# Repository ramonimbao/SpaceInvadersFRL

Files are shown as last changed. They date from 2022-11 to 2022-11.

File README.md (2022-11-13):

# Space Invaders FRL

  
Photo by migfernando#2194

## Disclaimer

Basically, the Space Invaders and the individual Space Invader icons belong solely to Taito Corporation, and cannot be included in this repository. 

## Files

### Case

Case files and drawings are in the `case` folder.

The files are designed for CNC machining and include the drawings for ttap callouts and such. For 3D printing, you may need to modify the files.

### Plate

Plate files are in the `plate` folder.

A DXF file is included for machining/laser cutting.

KiCAD files for an FR4 plate are in the `plate/sifrl-plate` folder. Gerber files are in the `plate/sifrl-plate/JLCPCB/gerbers` folder.

Either way, **order 1mm thick plates**.

### PCB

Main PCB files are in the `pcb` folder.

Gerber files are in the `pcb/JLCPCB/gerbers` folder. Assembly files are in `pcb/JLCPCB/assembly folder`.

A 1.6mm thick PCB should be fine. 1.2mm could work.

### Firmware

The keyboard uses [QMK/VIAL](https://get.vial.today/). Firmware file for it is in the `firmware` folder.

QMK source files for the board are in [this repo](https://github.com/ramonimbao/vial-qmk/tree/kb/sifrl/keyboards/ramonimbao/sifrl).

## Daughterboard

The board uses [my own version of the squatterboard](https://github.com/ramonimbao/squatterboard-v1.5). See the repo for more details.

## Parts Needed

| Qty | Part | URL | Notes |
| --- | ---- | --- | ----- |
| 2 | M3x10 Cap Head Screw | https://www.mcmaster.com/95263A134 | For the case |
| 9 | M2.5x6 Button Head Screw | https://www.mcmaster.com/92095A458 |For the plate |
| 2 | M3x6 Cap Head Screw | https://www.mcmaster.com/92095A179 | For the daughterboard
| 1 | 50mm 4-pin JST-SH cable | https://www.digikey.com/short/q0md9qh8 |  Longer is better if you want to be able to reassemble it often |

## License

The files in this repository are licensed under CERN-OHL-P-2.0. See the LICENSE file for more details.

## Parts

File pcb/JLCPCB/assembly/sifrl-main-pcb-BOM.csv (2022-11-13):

Comment | Designator | Footprint | LCSC
100nF | C1,C2,C4,C5,C6,C7,C8,C9,C10,C11,C17 | Capacitor_SMD:C_0402_1005Metric | C1525
30pF | C15,C16 | Capacitor_SMD:C_0402_1005Metric | C1570
1uF | C3,C12,C13,C14 | Capacitor_SMD:C_0603_1608Metric | C15849
1N4148 | D1,D2,D3,D4,D5,D6,D7,D8,D9,D10,D11,D12,D13,D14,D15,D16,D17,D18,D19,D20,D21,D22,D23,D24,D25,D26,D27,D28,D29,D30,D31,D32,D33,D34,D35,D36,D37,D38,D39,D40,D41,D42,D43,D44,D45,D46,D47,D48,D49,D50,D51,D52,D53,D54,D55,D56,D57,D58,D59,D60,D61,D62,D63,D64,D65,D66,D67,D68,D69,D70,D71,D72 | random-keyboard-parts:D_SOD-123-Pretty | C81598
500mA | F1 | Fuse:Fuse_1206_3216Metric_Pad1.42x1.75mm_HandSolder | C70076
SM04B | J1 | Connector_JST:JST_SH_SM04B-SRSS-TB_1x04-1MP_P1.00mm_Horizontal | C160404
10K | R1 | Resistor_SMD:R_0402_1005Metric | C25744
1k | R2 | Resistor_SMD:R_0402_1005Metric | C11702
27 | R3,R4 | Resistor_SMD:R_0603_1608Metric | C25190
SW_Push | SW1 | Button_Switch_SMD:SW_SPST_TL3342 | C318884
XC6206P332MR | U1 | Package_TO_SOT_SMD:SOT-23 | C5446
RP2040 | U2 | random-keyboard-parts:RP2040-QFN-56 | C2040
SRV05-4 | U3 | Package_TO_SOT_SMD:SOT-23-6 | C85364
W25Q128JVS | U4 | Package_SO:SOIC-8_5.23x5.23mm_P1.27mm | C97521
12MHz | Y1 | Crystal:Crystal_SMD_3225-4Pin_3.2x2.5mm | C9002

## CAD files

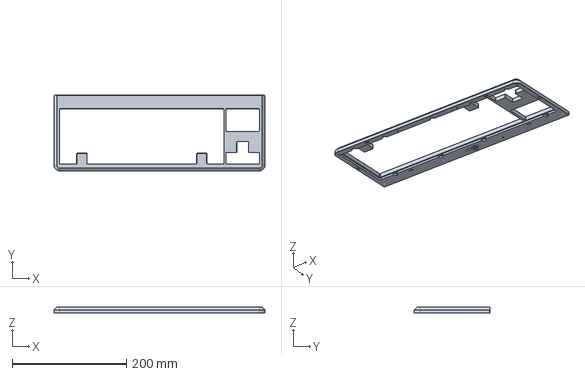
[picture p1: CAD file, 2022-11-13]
case/SI FRL - Top (WKL).step
368.7 x 132.3 x 10.5 mm

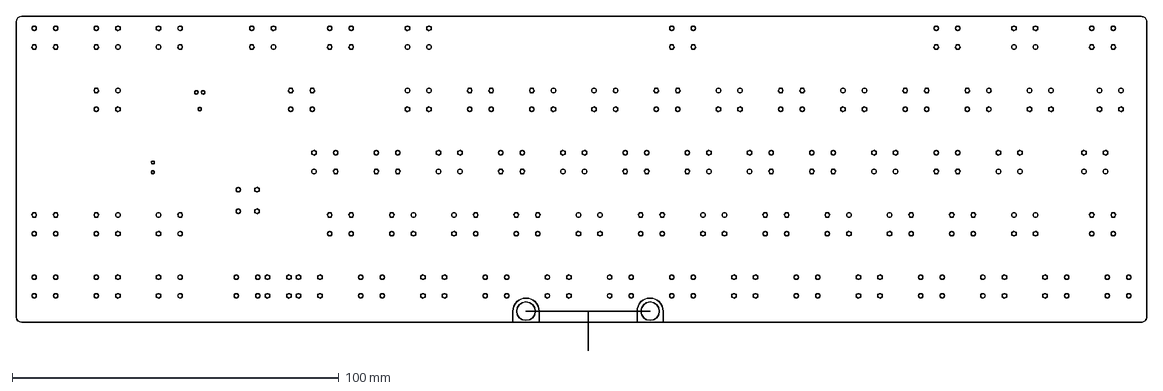
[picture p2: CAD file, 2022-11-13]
pcb/pcb-cutouts.dxf
346.1 x 102.3 mm

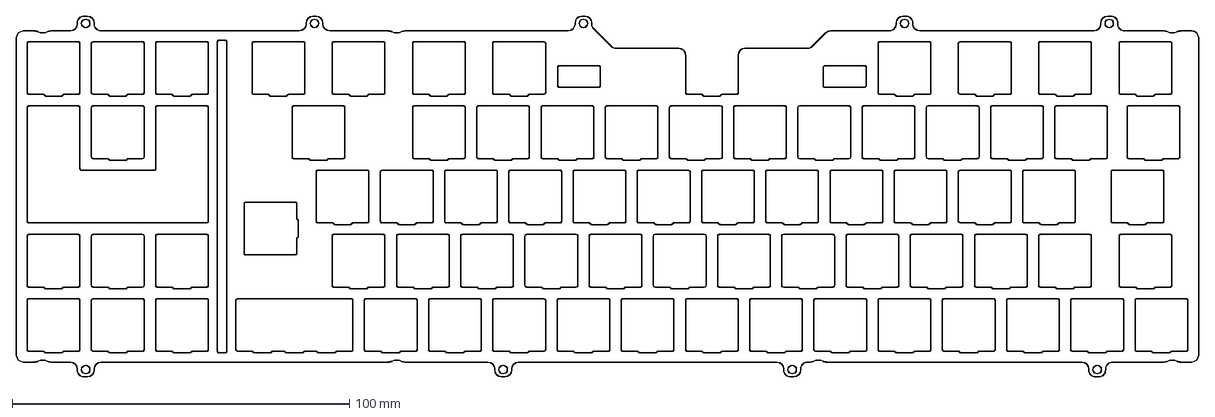
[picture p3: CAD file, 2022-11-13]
plate/sifrl-plate.dxf
350.6 x 106.9 mm

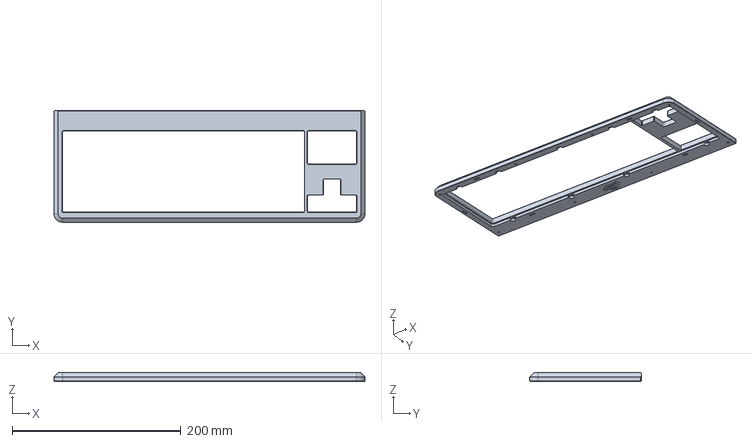
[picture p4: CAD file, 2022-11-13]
case/SI FRL - Top (WK).step
368.7 x 132.3 x 10.5 mm

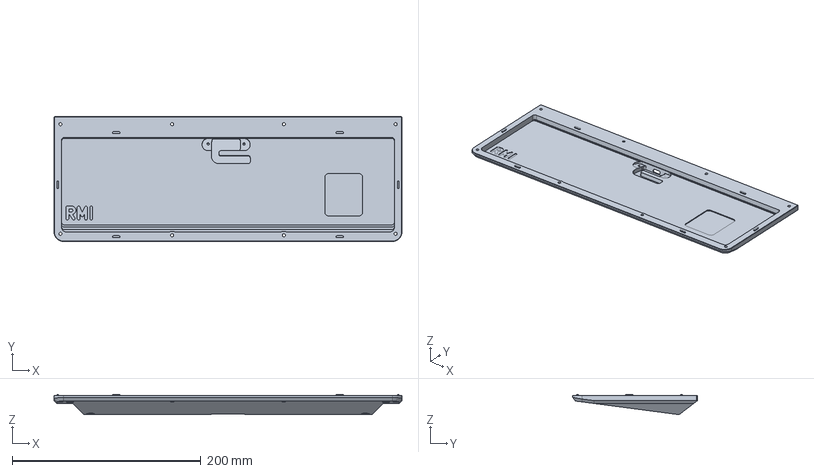
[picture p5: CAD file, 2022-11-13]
case/SI FRL - Bottom.step
368.7 x 132.3 x 21.5 mm

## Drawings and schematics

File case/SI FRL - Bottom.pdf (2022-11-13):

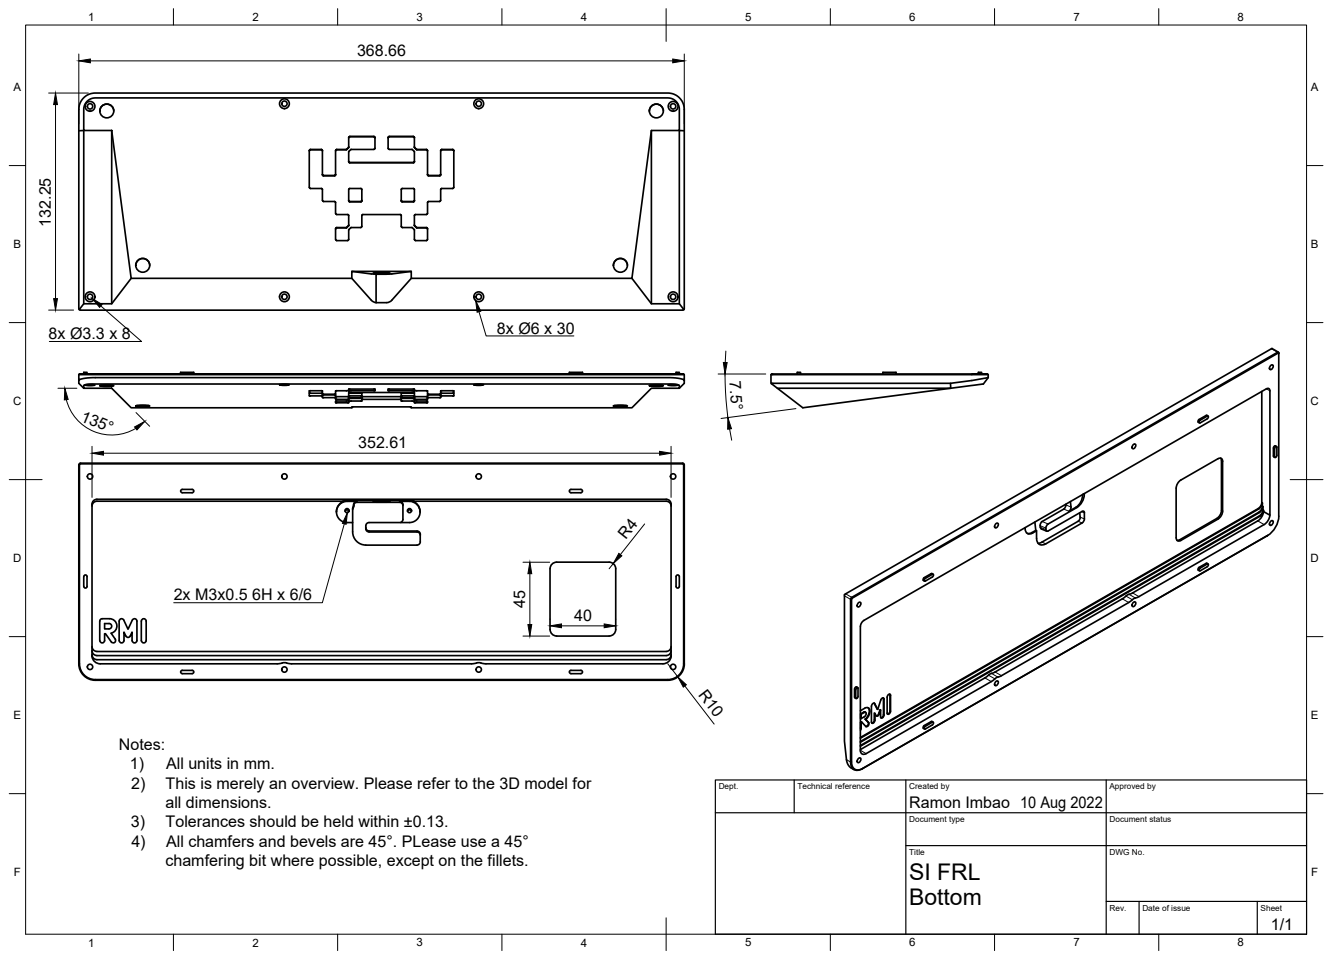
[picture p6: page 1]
Title; DWG No.; Rev.; Date of issue; Sheet; SI FRL

Notes:
1) All units in mm.
2) This is merely an overview. Please refer to the 3D model for
all dimensions.
3) Tolerances should be held within ±0.13.
4) All chamfers and bevels are 45°. PLease use a 45°
chamfering bit where possible, except on the fillets.

Dept. | Technical reference | Created by Ramon Imbao 10 Aug 2022 | Approved by

Document type | Document status

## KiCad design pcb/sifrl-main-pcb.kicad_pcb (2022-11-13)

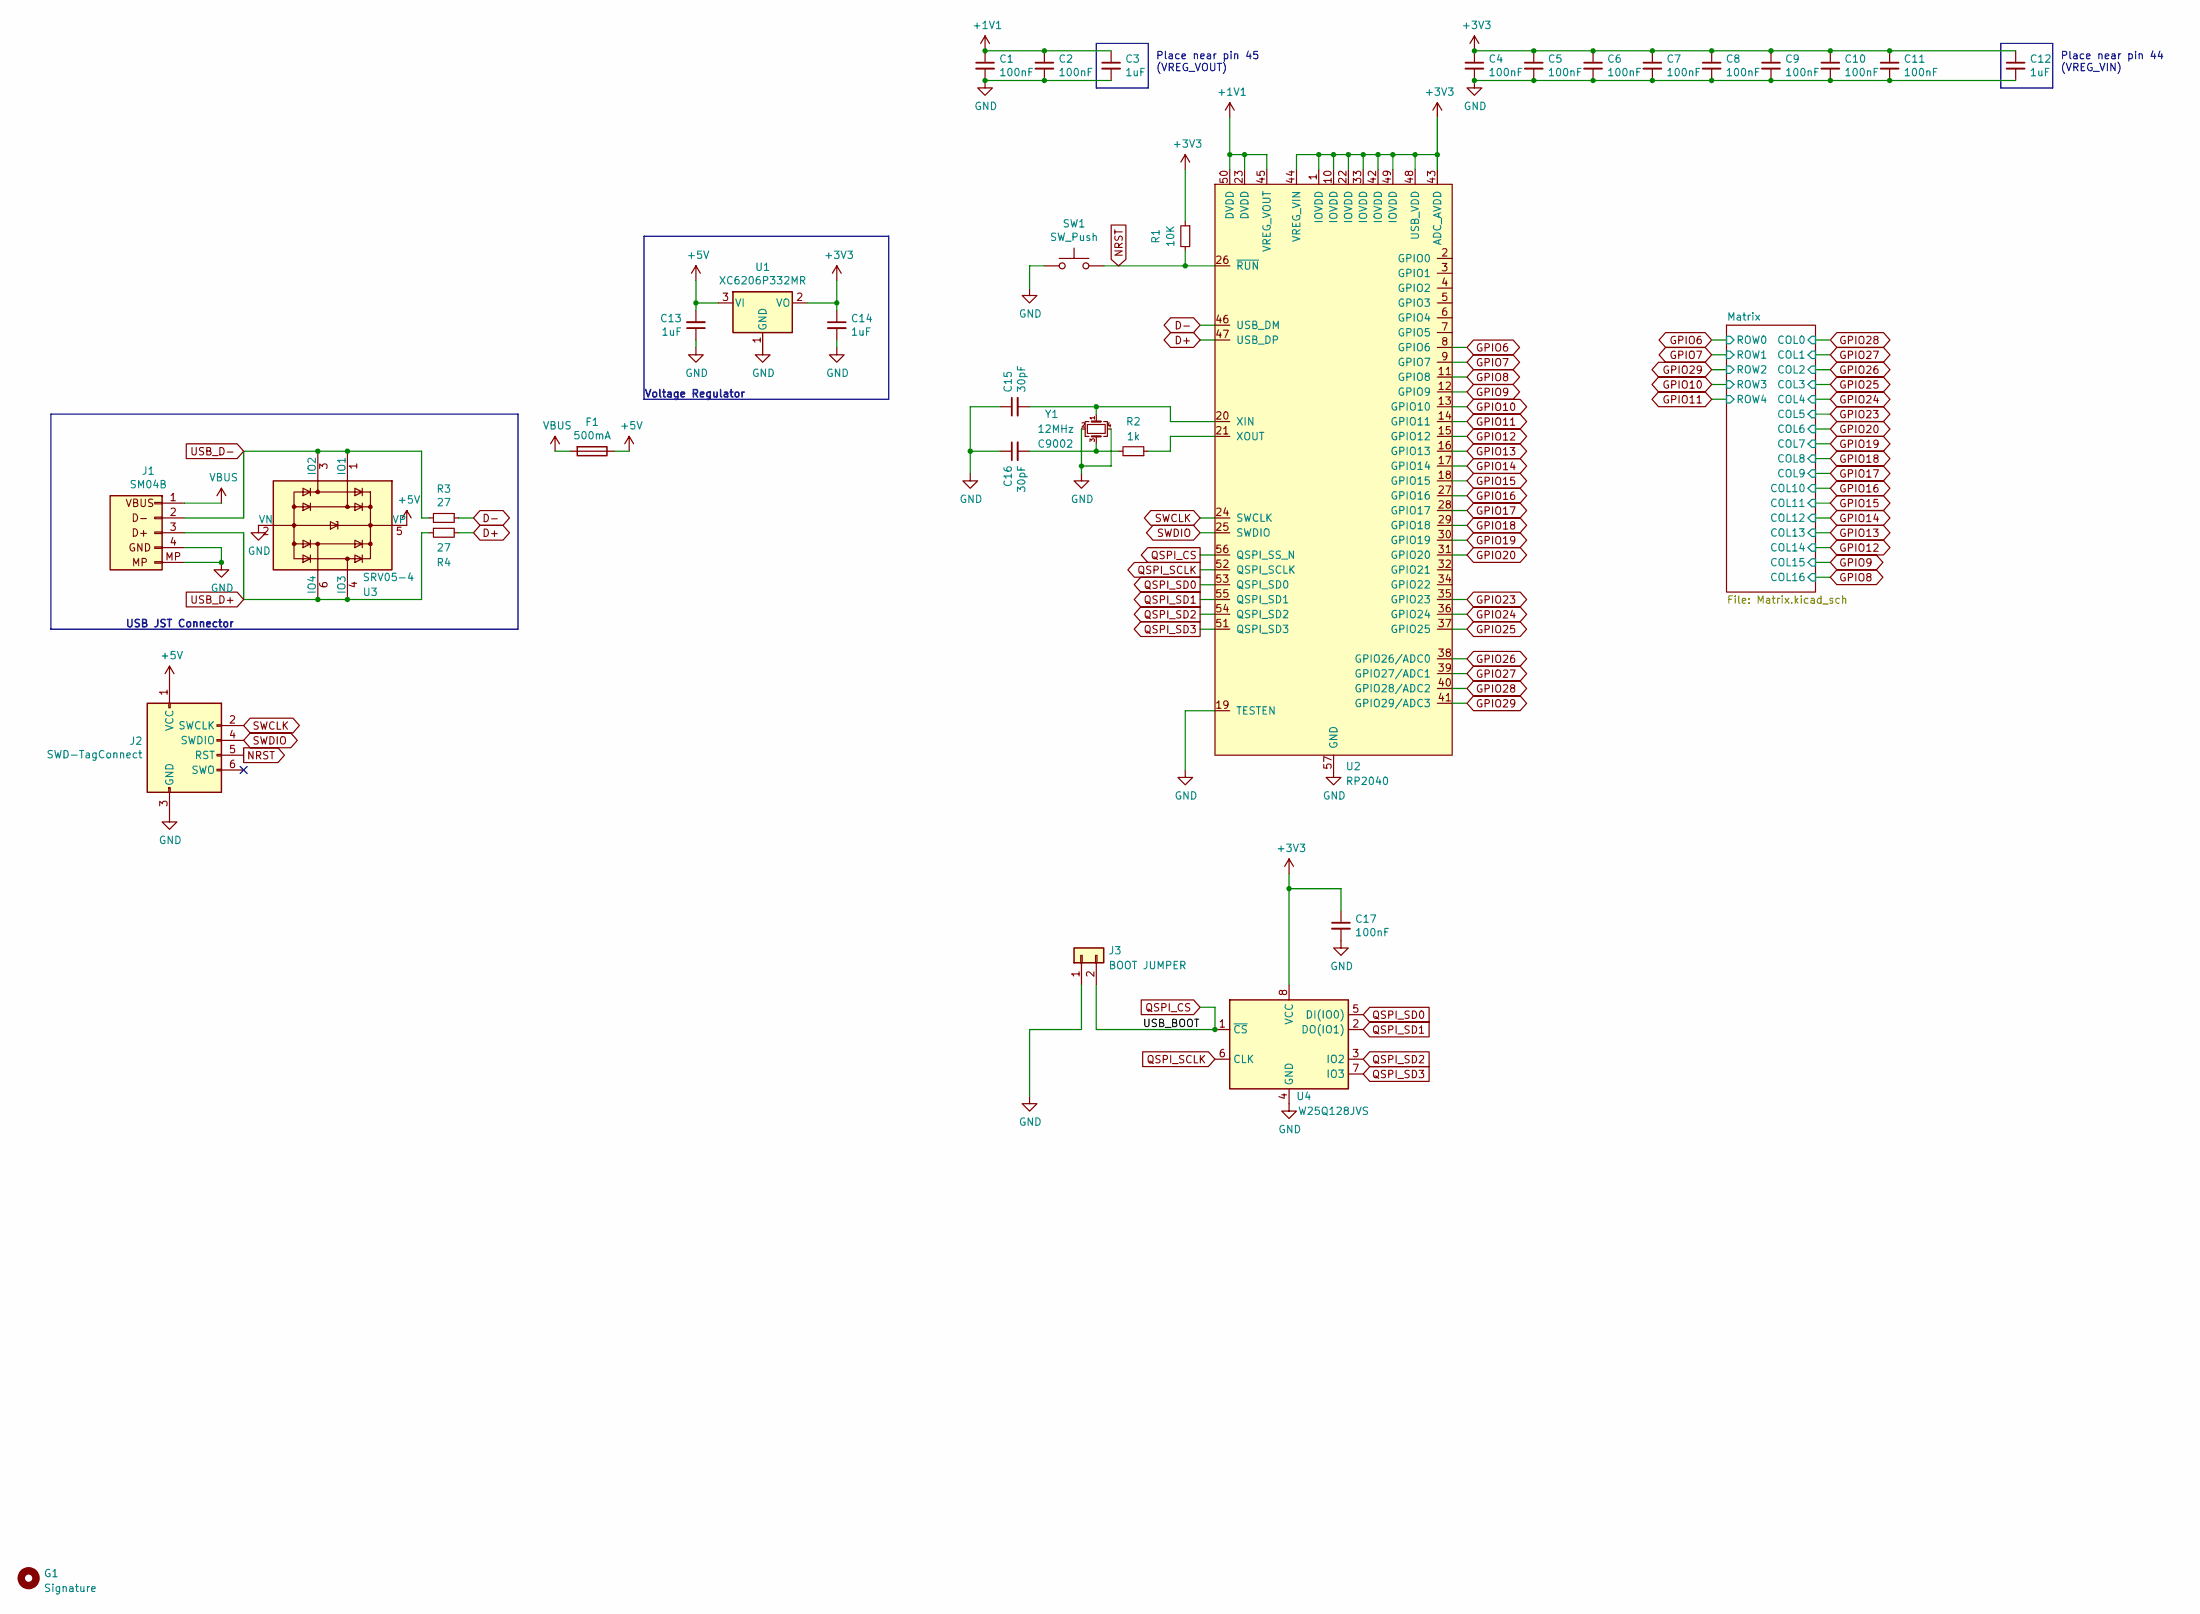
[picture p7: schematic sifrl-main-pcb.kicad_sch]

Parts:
C1, C2, C4, C5, C6, C7, C8, C9, C10, C11, C17: 100nF; C_0402_1005Metric
C3, C12, C13, C14: 1uF; C_0603_1608Metric
C15, C16: 30pF; C_0402_1005Metric
F1: 500mA; Fuse_1206_3216Metric_Pad1.42x1.75mm_HandSolder
G1: Signature
J1: SM04B; JST_SH_SM04B-SRSS-TB_1x04-1MP_P1.00mm_Horizontal
J2: SWD-TagConnect; Tag-Connect_TC2030-IDC-NL_2x03_P1.27mm_Vertical
J3: BOOT JUMPER; PinSocket_1x02_P2.54mm_Vertical
R1: 10K; R_0402_1005Metric
R2: 1k; R_0402_1005Metric
R3, R4: 27; R_0603_1608Metric
SW1: SW_Push; SW_SPST_TL3342
U1: XC6206P332MR; SOT-23
U2: RP2040; RP2040-QFN-56
U3: SRV05-4; SOT-23-6
U4: W25Q128JVS; SOIC-8_5.23x5.23mm_P1.27mm
Y1: 12MHz; Crystal_SMD_3225-4Pin_3.2x2.5mm; LCSC C9002

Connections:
+1V1: C1.1, C2.1, C3.1, U2.23 (DVDD), U2.45 (VREG_VOUT), U2.50 (DVDD)
+3V3: C4.1, C5.1, C6.1, C7.1, C8.1, C9.1, C10.1, C11.1, C12.1, C14.1, C17.1, R1.1, U1.2 (VO), U2.1 (IOVDD), U2.10 (IOVDD), U2.22 (IOVDD), U2.33 (IOVDD), U2.42 (IOVDD), U2.43 (ADC_AVDD), U2.44 (VREG_VIN), U2.48 (USB_VDD), U2.49 (IOVDD), U4.8 (VCC)
+5V: C13.2, F1.1, J2.1 (VCC), U1.3 (VI), U3.5 (VP)
D+: R4.2, U2.47 (USB_DP)
D-: R3.1, U2.46 (USB_DM)
GND: C1.2, C2.2, C3.2, C4.2, C5.2, C6.2, C7.2, C8.2, C9.2, C10.2, C11.2, C12.2, C13.1, C14.2, C15.1, C16.1, C17.2, J1.4 (GND), J1.MP (Mounting), J2.3 (GND), J3.1, SW1.1, U1.1 (GND), U2.19 (TESTEN), U2.57 (GND), U3.2 (VN), U4.4 (GND), Y1.2, Y1.4
GPIO6: U2.8 (GPIO6); also elsewhere on the board
GPIO7: U2.9 (GPIO7); also elsewhere on the board
GPIO8: U2.11 (GPIO8); also elsewhere on the board
GPIO9: U2.12 (GPIO9); also elsewhere on the board
GPIO10: U2.13 (GPIO10); also elsewhere on the board
GPIO11: U2.14 (GPIO11); also elsewhere on the board
GPIO12: U2.15 (GPIO12); also elsewhere on the board
GPIO13: U2.16 (GPIO13); also elsewhere on the board
GPIO14: U2.17 (GPIO14); also elsewhere on the board
GPIO15: U2.18 (GPIO15); also elsewhere on the board
GPIO16: U2.27 (GPIO16); also elsewhere on the board
GPIO17: U2.28 (GPIO17); also elsewhere on the board
GPIO18: U2.29 (GPIO18); also elsewhere on the board
GPIO19: U2.30 (GPIO19); also elsewhere on the board
GPIO20: U2.31 (GPIO20); also elsewhere on the board
GPIO23: U2.35 (GPIO23); also elsewhere on the board
GPIO24: U2.36 (GPIO24); also elsewhere on the board
GPIO25: U2.37 (GPIO25); also elsewhere on the board
GPIO26: U2.38 (GPIO26/ADC0); also elsewhere on the board
GPIO27: U2.39 (GPIO27/ADC1); also elsewhere on the board
GPIO28: U2.40 (GPIO28/ADC2); also elsewhere on the board
GPIO29: U2.41 (GPIO29/ADC3); also elsewhere on the board
NRST: J2.5 (RST), R1.2, SW1.2, U2.26 (~RUN)
unnamed: C15.2, U2.20 (XIN), Y1.1
unnamed: C16.2, R2.2, Y1.3
unnamed: R2.1, U2.21 (XOUT)
QSPI_CS: J3.2, U2.56 (QSPI_SS_N), U4.1 (~CS)
QSPI_SCLK: U2.52 (QSPI_SCLK), U4.6 (CLK)
QSPI_SD0: U2.53 (QSPI_SD0), U4.5 (DI(IO0))
QSPI_SD1: U2.55 (QSPI_SD1), U4.2 (DO(IO1))
QSPI_SD2: U2.54 (QSPI_SD2), U4.3 (IO2)
QSPI_SD3: U2.51 (QSPI_SD3), U4.7 (IO3)
SWCLK: J2.2 (SWCLK), U2.24 (SWCLK)
SWDIO: J2.4 (SWDIO), U2.25 (SWDIO)
USB_D+: J1.3 (D+), R4.1, U3.4 (IO3), U3.6 (IO4)
USB_D-: J1.2 (D-), R3.2, U3.1 (IO1), U3.3 (IO2)
VBUS: F1.2, J1.1 (VBUS)

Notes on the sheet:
Voltage Regulator
Place near pin 45 (VREG_VOUT)
USB JST Connector
Place near pin 44 (VREG_VIN)

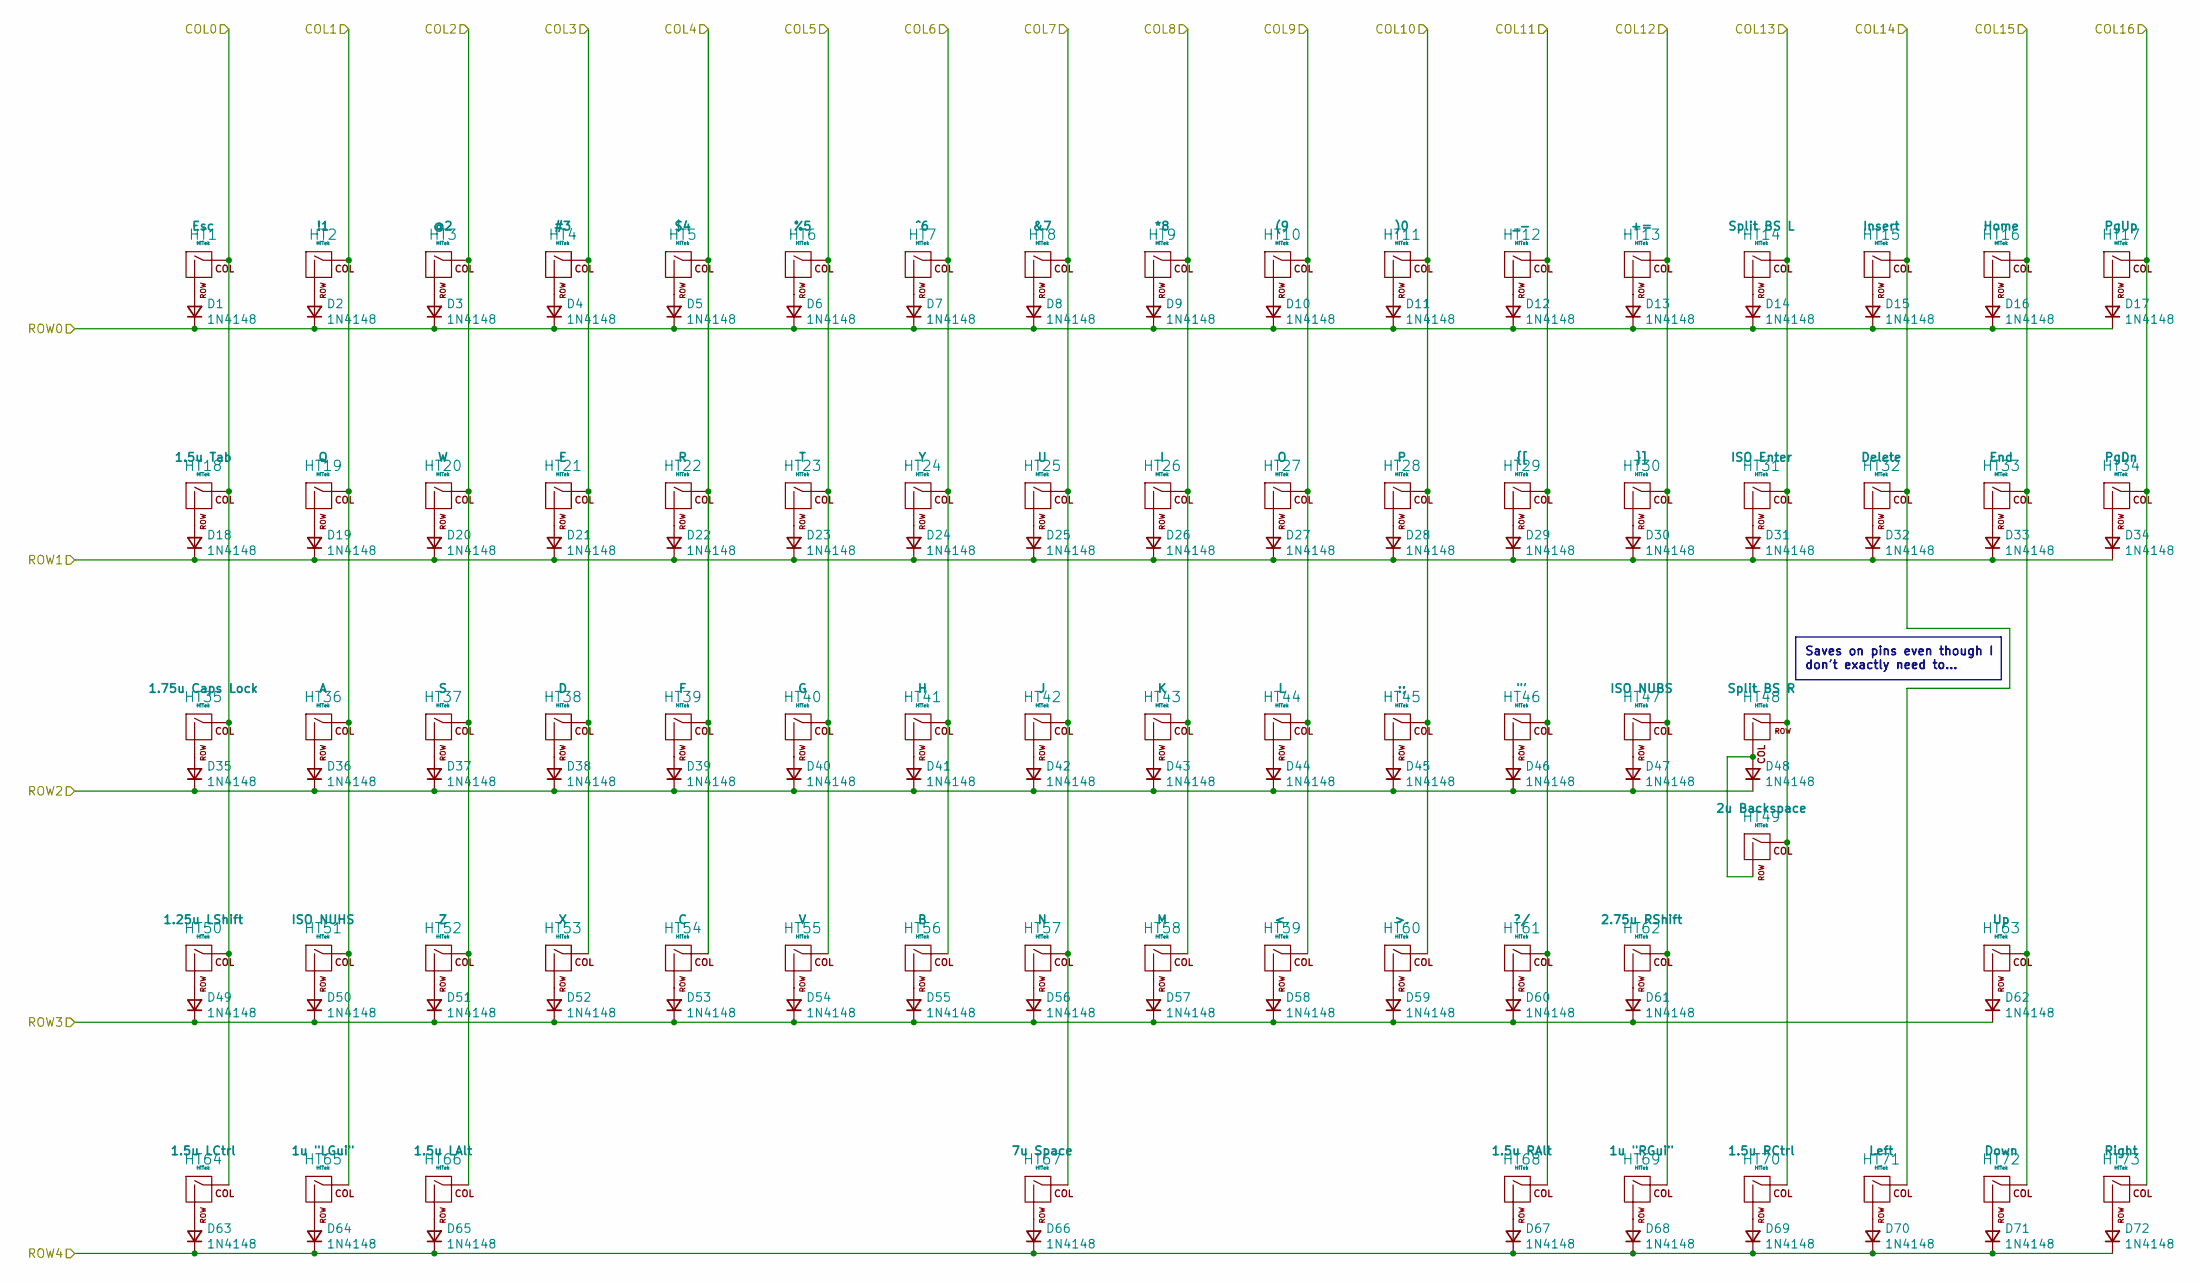
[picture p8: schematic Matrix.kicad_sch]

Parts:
D1, D2, D3, D4, D5, D6, D7, D8, D9, D10, D11, D12, D13, D14, D15, D16, D17, D18, D19, D20, D21, D22, D23, D24, D25, D26, D27, D28, D29, D30, D31, D32, D33, D34, D35, D36, D37, D38, D39, D40, D41, D42, D43, D44, D45, D46, D47, D48, D49, D50, D51, D52, D53, D54, D55, D56, D57, D58, D59, D60, D61, D62, D63, D64, D65, D66, D67, D68, D69, D70, D71, D72: 1N4148; D_SOD-123-Pretty
HT1, HT2, HT3, HT4, HT5, HT6, HT7, HT8, HT9, HT10, HT11, HT12, HT13, HT15, HT16, HT17, HT19, HT20, HT21, HT22, HT23, HT24, HT25, HT26, HT27, HT28, HT29, HT30, HT32, HT33, HT34, HT36, HT37, HT38, HT39, HT40, HT41, HT42, HT43, HT44, HT45, HT46, HT47, HT48, HT51, HT52, HT53, HT54, HT55, HT56, HT57, HT58, HT59, HT60, HT61, HT63, HT65, HT69, HT71, HT72, HT73: HiTek; Hitek725-1U
HT14: HiTek; Hitek725-1U-DudPad
HT18, HT64, HT66, HT68, HT70: HiTek; Hitek725-1.5U
HT31: HiTek; Hitek725-ISO
HT35: HiTek; Hitek725-1.75U
HT49: HiTek; Hitek725-2U-DudPad
HT50: HiTek; Hitek725-1.25U
HT62: HiTek; Hitek725-2.75U
HT67: HiTek; Hitek725-7U

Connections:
GPIO6: D1.1 (K), D2.1 (K), D3.1 (K), D4.1 (K), D5.1 (K), D6.1 (K), D7.1 (K), D8.1 (K), D9.1 (K), D10.1 (K), D11.1 (K), D12.1 (K), D13.1 (K), D14.1 (K), D15.1 (K), D16.1 (K), D17.1 (K); also elsewhere on the board
GPIO7: D18.1 (K), D19.1 (K), D20.1 (K), D21.1 (K), D22.1 (K), D23.1 (K), D24.1 (K), D25.1 (K), D26.1 (K), D27.1 (K), D28.1 (K), D29.1 (K), D30.1 (K), D31.1 (K), D32.1 (K), D33.1 (K), D34.1 (K); also elsewhere on the board
GPIO8: HT17.1 (COL), HT34.1 (COL), HT73.1 (COL); also elsewhere on the board
GPIO9: HT16.1 (COL), HT33.1 (COL), HT63.1 (COL), HT72.1 (COL); also elsewhere on the board
GPIO10: D49.1 (K), D50.1 (K), D51.1 (K), D52.1 (K), D53.1 (K), D54.1 (K), D55.1 (K), D56.1 (K), D57.1 (K), D58.1 (K), D59.1 (K), D60.1 (K), D61.1 (K), D62.1 (K); also elsewhere on the board
GPIO11: D63.1 (K), D64.1 (K), D65.1 (K), D66.1 (K), D67.1 (K), D68.1 (K), D69.1 (K), D70.1 (K), D71.1 (K), D72.1 (K); also elsewhere on the board
GPIO12: HT15.1 (COL), HT32.1 (COL), HT71.1 (COL); also elsewhere on the board
GPIO13: HT14.1 (COL), HT31.1 (COL), HT48.2 (ROW), HT49.1 (COL), HT70.1 (COL); also elsewhere on the board
GPIO14: HT13.1 (COL), HT30.1 (COL), HT47.1 (COL), HT62.1 (COL), HT69.1 (COL); also elsewhere on the board
GPIO15: HT12.1 (COL), HT29.1 (COL), HT46.1 (COL), HT61.1 (COL), HT68.1 (COL); also elsewhere on the board
GPIO16: HT11.1 (COL), HT28.1 (COL), HT45.1 (COL), HT60.1 (COL); also elsewhere on the board
GPIO17: HT10.1 (COL), HT27.1 (COL), HT44.1 (COL), HT59.1 (COL); also elsewhere on the board
GPIO18: HT9.1 (COL), HT26.1 (COL), HT43.1 (COL), HT58.1 (COL); also elsewhere on the board
GPIO19: HT8.1 (COL), HT25.1 (COL), HT42.1 (COL), HT57.1 (COL), HT67.1 (COL); also elsewhere on the board
GPIO20: HT7.1 (COL), HT24.1 (COL), HT41.1 (COL), HT56.1 (COL); also elsewhere on the board
GPIO23: HT6.1 (COL), HT23.1 (COL), HT40.1 (COL), HT55.1 (COL); also elsewhere on the board
GPIO24: HT5.1 (COL), HT22.1 (COL), HT39.1 (COL), HT54.1 (COL); also elsewhere on the board
GPIO25: HT4.1 (COL), HT21.1 (COL), HT38.1 (COL), HT53.1 (COL); also elsewhere on the board
GPIO26: HT3.1 (COL), HT20.1 (COL), HT37.1 (COL), HT52.1 (COL), HT66.1 (COL); also elsewhere on the board
GPIO27: HT2.1 (COL), HT19.1 (COL), HT36.1 (COL), HT51.1 (COL), HT65.1 (COL); also elsewhere on the board
GPIO28: HT1.1 (COL), HT18.1 (COL), HT35.1 (COL), HT50.1 (COL), HT64.1 (COL); also elsewhere on the board
GPIO29: D35.1 (K), D36.1 (K), D37.1 (K), D38.1 (K), D39.1 (K), D40.1 (K), D41.1 (K), D42.1 (K), D43.1 (K), D44.1 (K), D45.1 (K), D46.1 (K), D47.1 (K), D48.1 (K); also elsewhere on the board
unnamed: D1.2 (A), HT1.2 (ROW)
unnamed: D2.2 (A), HT2.2 (ROW)
unnamed: D3.2 (A), HT3.2 (ROW)
unnamed: D4.2 (A), HT4.2 (ROW)
unnamed: D5.2 (A), HT5.2 (ROW)
unnamed: D6.2 (A), HT6.2 (ROW)
unnamed: D7.2 (A), HT7.2 (ROW)
unnamed: D8.2 (A), HT8.2 (ROW)
unnamed: D9.2 (A), HT9.2 (ROW)
unnamed: D10.2 (A), HT10.2 (ROW)
unnamed: D11.2 (A), HT11.2 (ROW)
unnamed: D12.2 (A), HT12.2 (ROW)
unnamed: D13.2 (A), HT13.2 (ROW)
unnamed: D14.2 (A), HT14.2 (ROW)
unnamed: D15.2 (A), HT15.2 (ROW)
unnamed: D16.2 (A), HT16.2 (ROW)
unnamed: D17.2 (A), HT17.2 (ROW)
unnamed: D18.2 (A), HT18.2 (ROW)
unnamed: D19.2 (A), HT19.2 (ROW)
unnamed: D20.2 (A), HT20.2 (ROW)
unnamed: D21.2 (A), HT21.2 (ROW)
unnamed: D22.2 (A), HT22.2 (ROW)
unnamed: D23.2 (A), HT23.2 (ROW)
unnamed: D24.2 (A), HT24.2 (ROW)
unnamed: D25.2 (A), HT25.2 (ROW)
unnamed: D26.2 (A), HT26.2 (ROW)
unnamed: D27.2 (A), HT27.2 (ROW)
unnamed: D28.2 (A), HT28.2 (ROW)
unnamed: D29.2 (A), HT29.2 (ROW)
unnamed: D30.2 (A), HT30.2 (ROW)
unnamed: D31.2 (A), HT31.2 (ROW)
unnamed: D32.2 (A), HT32.2 (ROW)
unnamed: D33.2 (A), HT33.2 (ROW)
unnamed: D34.2 (A), HT34.2 (ROW)
unnamed: D35.2 (A), HT35.2 (ROW)
unnamed: D36.2 (A), HT36.2 (ROW)
unnamed: D37.2 (A), HT37.2 (ROW)
unnamed: D38.2 (A), HT38.2 (ROW)
unnamed: D39.2 (A), HT39.2 (ROW)
unnamed: D40.2 (A), HT40.2 (ROW)
unnamed: D41.2 (A), HT41.2 (ROW)
unnamed: D42.2 (A), HT42.2 (ROW)
unnamed: D43.2 (A), HT43.2 (ROW)
unnamed: D44.2 (A), HT44.2 (ROW)
unnamed: D45.2 (A), HT45.2 (ROW)
unnamed: D46.2 (A), HT46.2 (ROW)
unnamed: D47.2 (A), HT47.2 (ROW)
unnamed: D48.2 (A), HT48.1 (COL), HT49.2 (ROW)
unnamed: D49.2 (A), HT50.2 (ROW)
unnamed: D50.2 (A), HT51.2 (ROW)
unnamed: D51.2 (A), HT52.2 (ROW)
unnamed: D52.2 (A), HT53.2 (ROW)
unnamed: D53.2 (A), HT54.2 (ROW)
unnamed: D54.2 (A), HT55.2 (ROW)
unnamed: D55.2 (A), HT56.2 (ROW)
unnamed: D56.2 (A), HT57.2 (ROW)
unnamed: D57.2 (A), HT58.2 (ROW)
unnamed: D58.2 (A), HT59.2 (ROW)
unnamed: D59.2 (A), HT60.2 (ROW)
unnamed: D60.2 (A), HT61.2 (ROW)
unnamed: D61.2 (A), HT62.2 (ROW)
unnamed: D62.2 (A), HT63.2 (ROW)
unnamed: D63.2 (A), HT64.2 (ROW)
unnamed: D64.2 (A), HT65.2 (ROW)
unnamed: D65.2 (A), HT66.2 (ROW)
unnamed: D66.2 (A), HT67.2 (ROW)
unnamed: D67.2 (A), HT68.2 (ROW)
unnamed: D68.2 (A), HT69.2 (ROW)
unnamed: D69.2 (A), HT70.2 (ROW)
unnamed: D70.2 (A), HT71.2 (ROW)
unnamed: D71.2 (A), HT72.2 (ROW)
unnamed: D72.2 (A), HT73.2 (ROW)

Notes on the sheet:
Saves on pins even though I don't exactly need to...

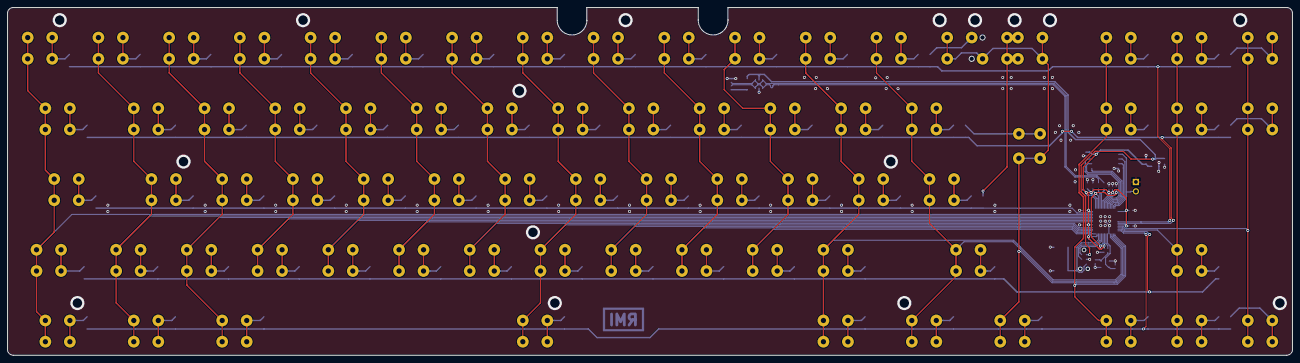
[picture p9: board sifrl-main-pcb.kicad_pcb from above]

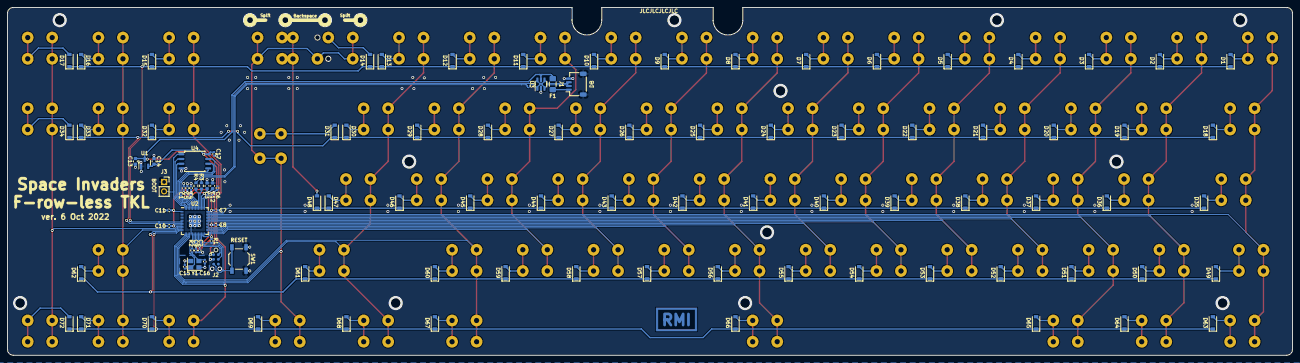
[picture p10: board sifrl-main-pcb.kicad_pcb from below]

Board: 2 copper layers, 346.1 x 93.7 mm, 177 parts (104 on the bottom side), 115 nets.

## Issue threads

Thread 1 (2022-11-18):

This is amazing

H0R1Z0N, 2022-11-18:
Dang, i wanted to probably got and go in the GB for the TKL plate/pcb ending before the end of the month for Space Invader board but this is what i would totally prefer. Is there a possibility for you to make a small variant with a slot for 1u keys where the windows and function keys should be normally ? I have one space defective board for the keycap and enough spare full AT102 iso from the Space Invasion GB that i could use 2 numdot for the 1u keys slot for windows keys and function keys ? I will be producing 2 for myself (linear and clicky) but my IRL friend would probably want one later on since i corrupted him to vintage space invader clicky.

Finally, i have looked the license but never seen that one before. Would it be possible for you to make a TL;DR explanation of it ? I am not a lawyer and i am unsure if my brother's wife who's one should be able to help me with that. Thank you.

ramonimbao, 2022-11-19:
@H0R1Z0N Do you mean a WK version? There's a WK version provided in the files.

You can also find a summary of the license here: https://choosealicense.com/licenses/cern-ohl-p-2.0/
